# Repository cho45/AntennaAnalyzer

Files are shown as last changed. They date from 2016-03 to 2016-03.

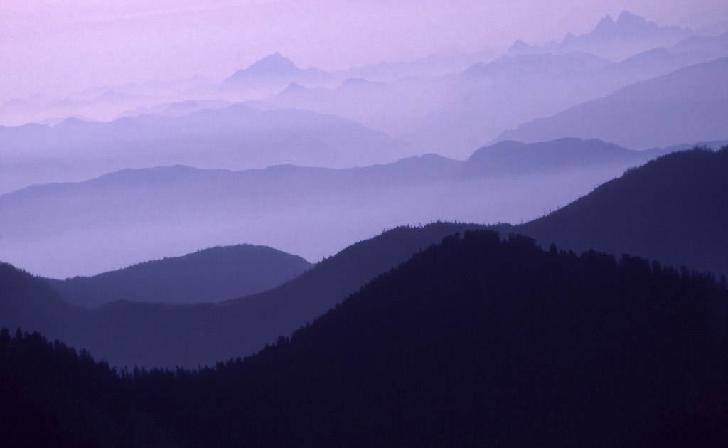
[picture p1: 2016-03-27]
software/cordova/www/bower_components/paper-scroll-header-panel/demo/images/bg1.jpg

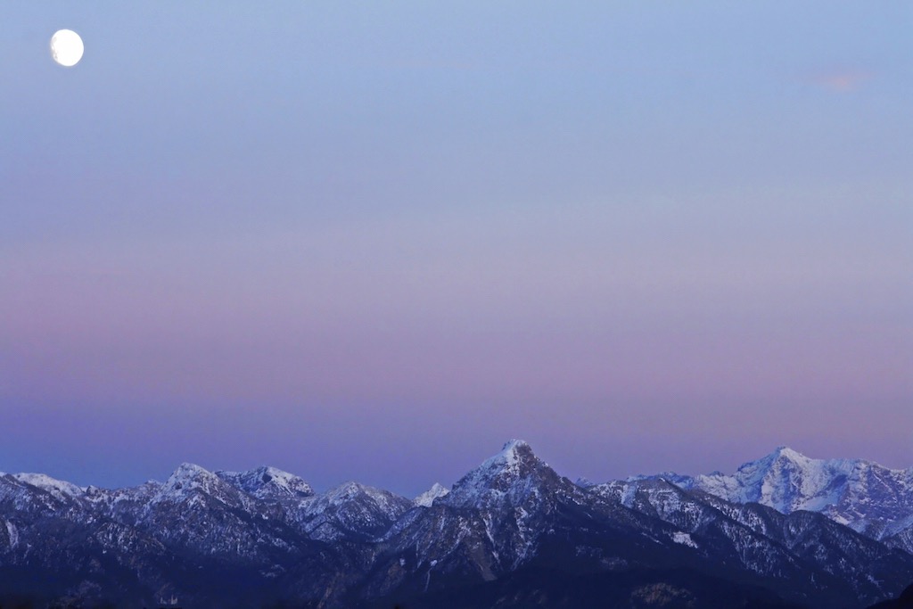
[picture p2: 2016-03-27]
software/cordova/www/bower_components/paper-scroll-header-panel/demo/images/bg3.jpg

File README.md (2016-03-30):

# AntennaAnalyzer

cho45's AntennaAnalyzer project

# Spec

 * Frequency range: 〜70MHz
 * Measures: SWR, R + j |X|

# Hardware

 * AD9851 DDS
 * Resistive bridge + AD8302 detector
 * LPC1114 (with mbed framework)
 * Bluetooth

# Android App Screen Shots







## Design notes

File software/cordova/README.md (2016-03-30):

## Development

```
npm install -g cordova
```

Emulate Bluetooth

```
cordova run browser
```

Device

```
cordova run android --device
```

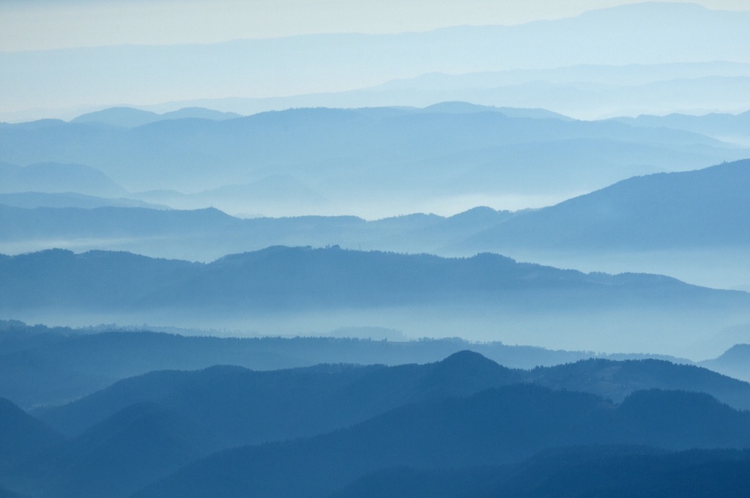
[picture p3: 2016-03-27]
software/cordova/www/bower_components/paper-scroll-header-panel/demo/images/bg4.jpg

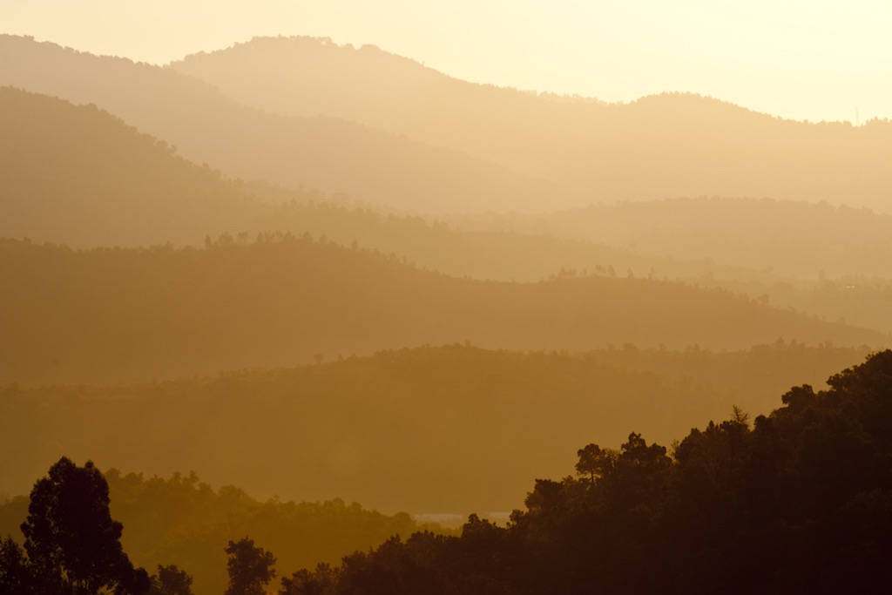
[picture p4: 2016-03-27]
software/cordova/www/bower_components/paper-scroll-header-panel/demo/images/bg2.jpg

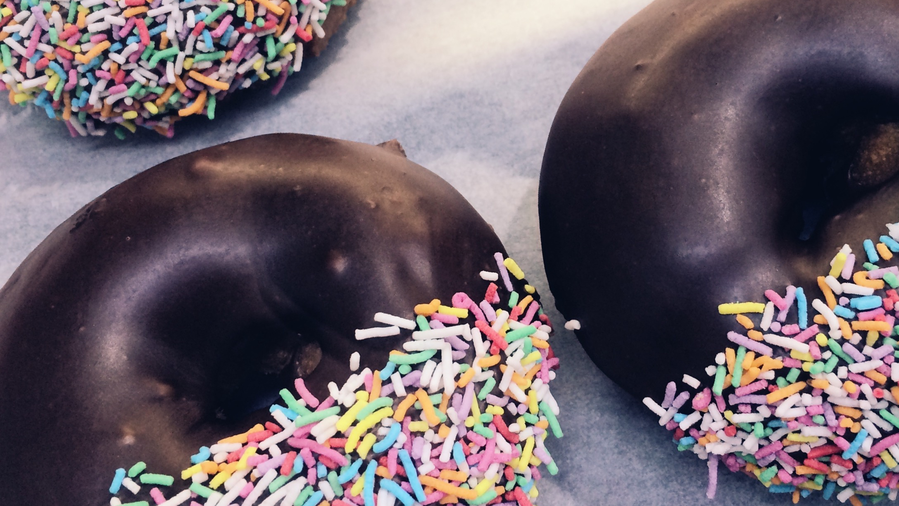
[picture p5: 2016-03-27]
software/cordova/www/bower_components/paper-card/demo/donuts.png

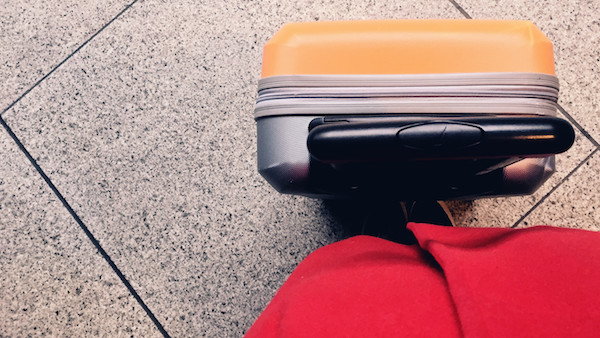
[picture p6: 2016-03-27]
software/cordova/www/bower_components/paper-card/demo/travel.png

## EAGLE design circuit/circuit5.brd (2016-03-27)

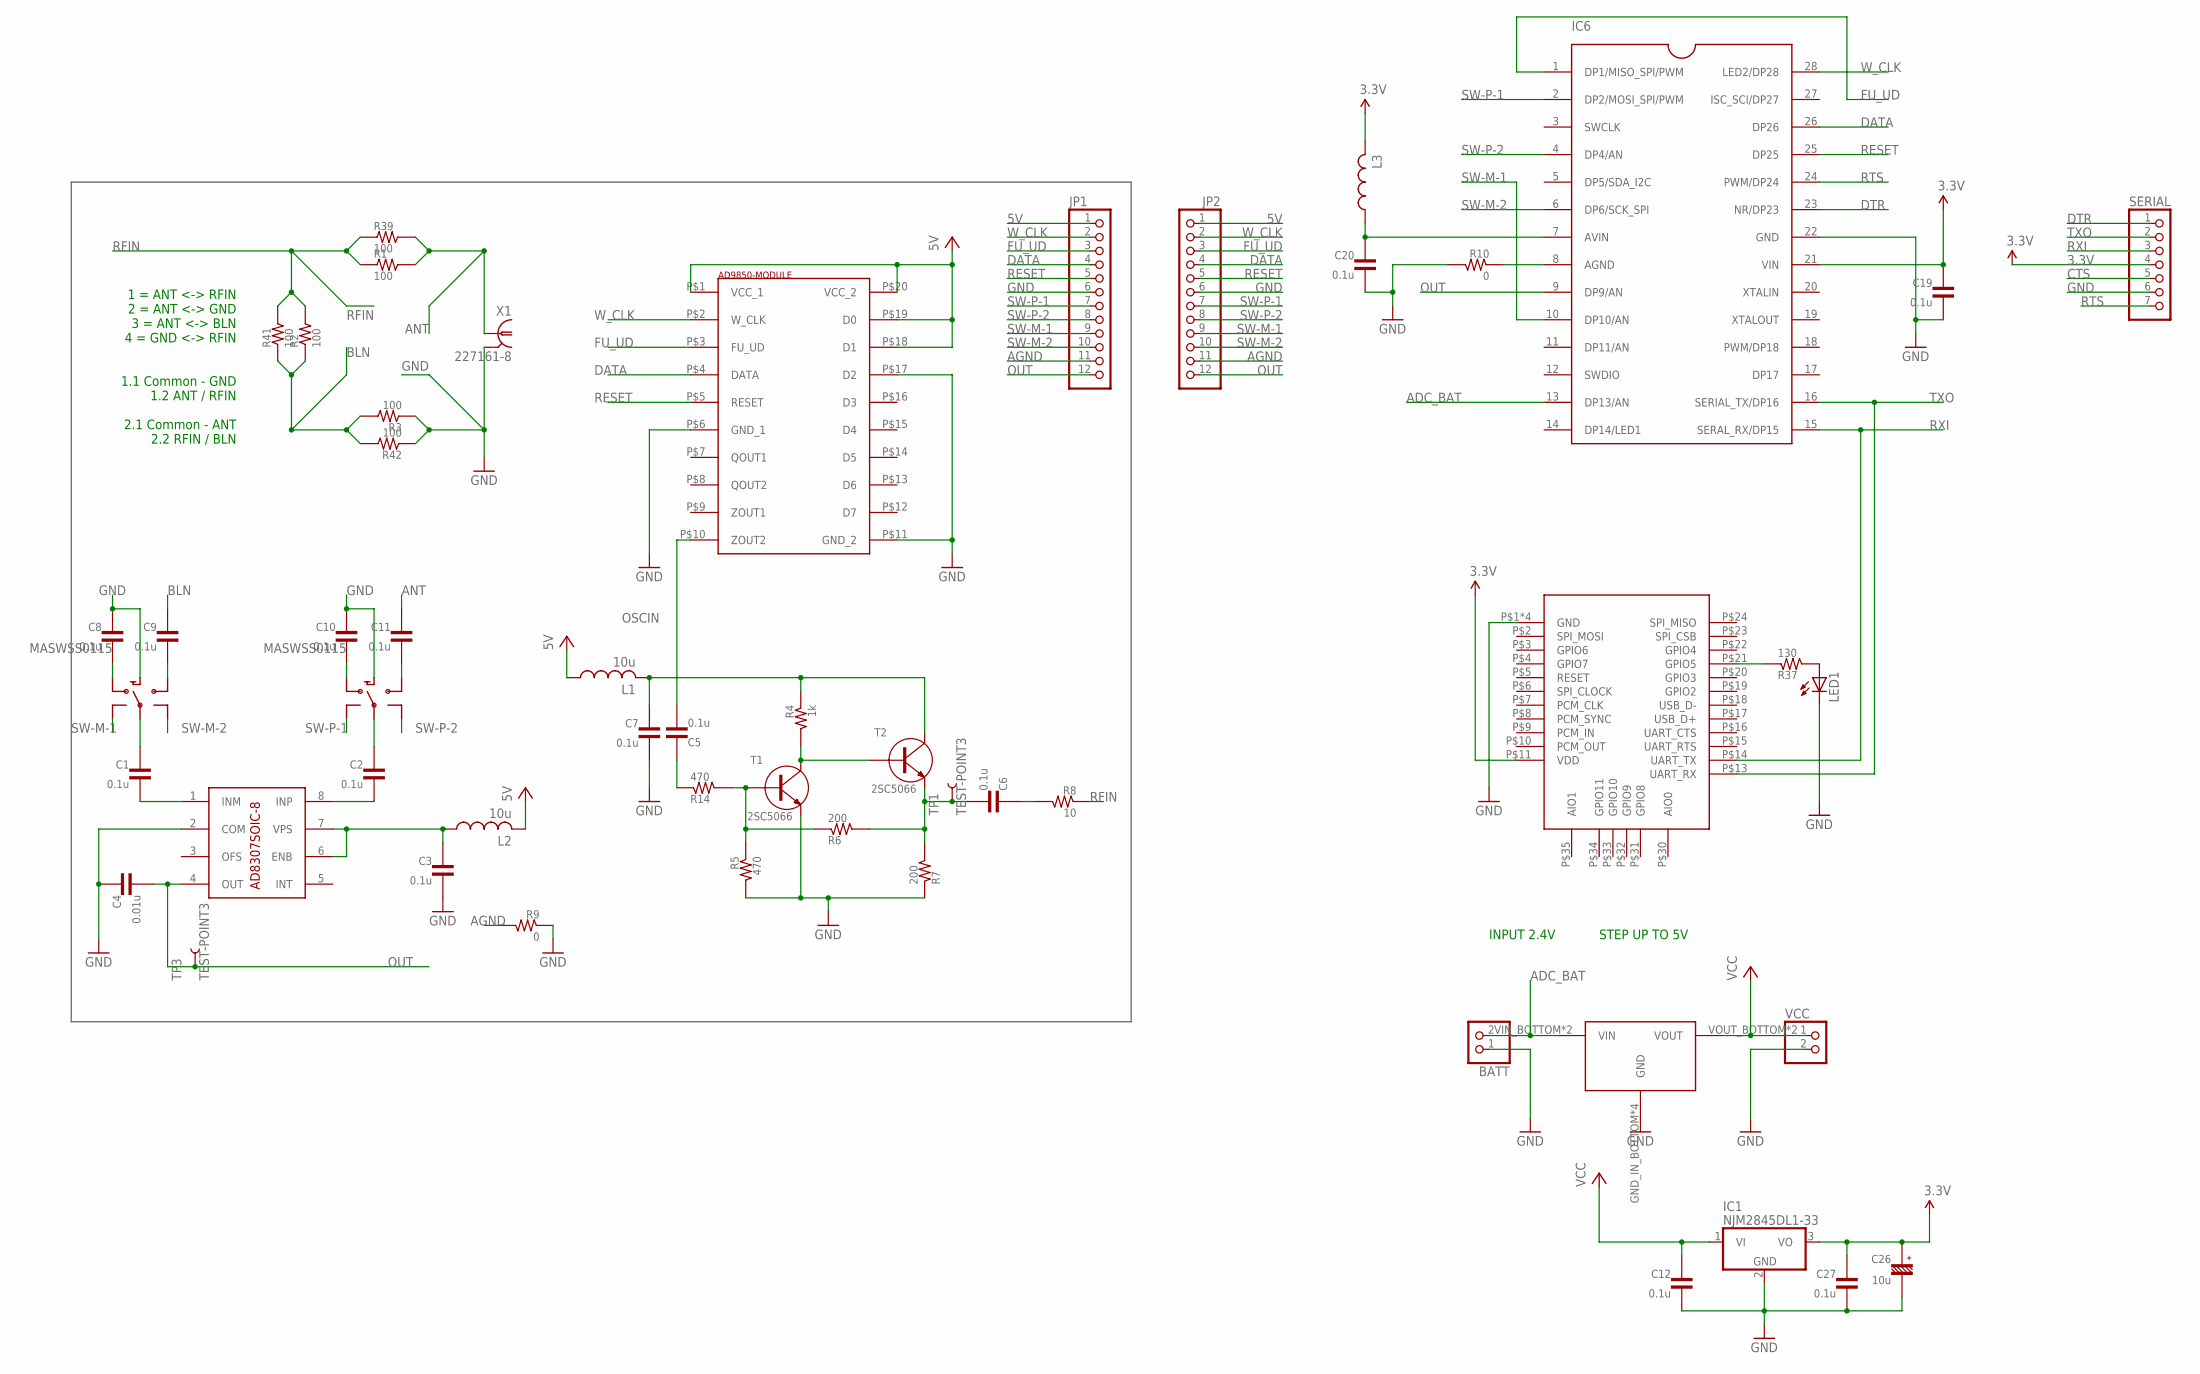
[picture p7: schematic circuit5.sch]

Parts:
BATT: PINHD-1X2; 1X02
C1, C2, C3, C5, C6, C7, C8, C9, C10, C11, C12, C19, C20, C27: 0.1u; CP1608
C4: 0.01u; CP1608
C26: 10u; 16V-4-2.54
IC1: NJM2845DL1-33; TO252
IC6: LPC1114FN28; DIP28
JP1, JP2: PINHD-1X12; 1X12
L1, L2: 10u; CP1608
L3: L-; CP1608
LED1: LED3MM
R1, R2, R3, R39, R41, R42: 100; CP1608
R4: 1k; CP1608
R5, R14: 470; CP1608
R6, R7: 200; CP1608
R8: 10; CP1608
R9, R10: 0; CP1608
R37: 130; CP1608
SERIAL: PINHD-1X7; 1X07
T1, T2: 2SC5066; SSM
TP1, TP3: TEST-POINT3; PAD.03X.03
U$1: AD9850-MODULE
U$2: RN-42
U$3: AD8307SOIC-8; SO08
U$4: DC-DCSX1308; DC-DC-SX1308
U$5, U$6: MASWSS0115; SOT363
VCC: PINHD-1X2; 1X02
X1: 227161-8; AMP_227161

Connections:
3.3V: C19.SMD1 (1), C26.+, C27.SMD1 (1), IC1.3 (VO), IC6.21 (VIN), L3.SMD2 (2), SERIAL.4, U$2.P$11 (VDD)
5V: C12.SMD1 (1), IC1.1 (VI), JP1.1, JP2.1, L1.SMD1 (1), L2.SMD2 (2), U$1.P$1 (VCC_1), U$1.P$18 (D1), U$1.P$19 (D0), U$1.P$20 (VCC_2), U$4.VOUT_BOTTOM (VOUT), U$4.VOUT_TOP (VOUT), VCC.1
+12V-ANALOG: C7.SMD1 (1), L1.SMD2 (2), R4.SMD1 (1), T2.P$3 (C)
ADC_BAT: BATT.2, IC6.13 (DP13/AN), U$4.VIN_BOTTOM (VIN), U$4.VIN_TOP (VIN)
AGND: IC6.8 (AGND), JP1.11, JP2.11, R9.SMD2 (2), R10.SMD1 (1)
ANT: C11.SMD1 (1), R1.SMD2 (2), R39.SMD2 (2), X1.1
BLN: C9.SMD1 (1), R2.SMD1 (1), R3.SMD2 (2), R41.SMD1 (1), R42.SMD2 (2)
CTS: SERIAL.5
DATA: IC6.26 (DP26), JP1.4, JP2.4, U$1.P$4 (DATA)
DTR: IC6.23 (NR/DP23), SERIAL.1
FU_UD: IC6.1 (DP1/MISO_SPI/PWM), JP1.3, JP2.3, U$1.P$3 (FU_UD)
GND: BATT.1, C3.SMD2 (2), C4.SMD1 (1), C7.SMD2 (2), C8.SMD1 (1), C10.SMD1 (1), C12.SMD2 (2), C19.SMD2 (2), C20.SMD2 (2), C26.-, C27.SMD2 (2), IC1.2 (GND), IC6.22 (GND), JP1.6, JP2.6, LED1.K (C), R3.SMD1 (1), R5.SMD2 (2), R7.SMD1 (1), R9.SMD1 (1), R10.SMD2 (2), R42.SMD1 (1), SERIAL.6, T1.P$2 (E), U$1.P$6 (GND_1), U$1.P$11 (GND_2), U$1.P$17 (D2), U$2.P$1 (GND), U$2.P$12 (GND), U$2.P$28 (GND), U$2.P$29 (GND), U$3.2 (COM), U$4.GND_IN_BOTTOM (GND), U$4.GND_IN_TOP (GND), U$4.GND_OUT_BOTTOM (GND), U$4.GND_OUT_TOP (GND), U$5.2 (GND), U$6.2 (GND), VCC.2, X1.2
unnamed: C2.SMD1 (1), U$6.5 (COMMON)
unnamed: C1.SMD1 (1), U$5.5 (COMMON)
unnamed: R4.SMD2 (2), T1.P$3 (C), T2.P$1 (B)
unnamed: R5.SMD1 (1), R6.SMD1 (1), R14.SMD2 (2), T1.P$1 (B)
unnamed: C8.SMD2 (2), U$5.3 (RF2)
unnamed: C6.SMD2 (2), R6.SMD2 (2), R7.SMD2 (2), T2.P$2 (E), TP1.P$1
unnamed: C1.SMD2 (2), U$3.1 (INM)
unnamed: C2.SMD2 (2), U$3.8 (INP)
unnamed: C3.SMD1 (1), L2.SMD1 (1), U$3.6 (ENB), U$3.7 (VPS)
unnamed: C9.SMD2 (2), U$5.1 (RF1)
unnamed: C10.SMD2 (2), U$6.3 (RF2)
unnamed: C5.SMD1 (1), R14.SMD1 (1)
unnamed: C11.SMD2 (2), U$6.1 (RF1)
unnamed: C6.SMD1 (1), R8.SMD2 (2)
unnamed: C20.SMD1 (1), IC6.7 (AVIN), L3.SMD1 (1)
unnamed: LED1.A, R37.SMD2 (2)
unnamed: R37.SMD1 (1), U$2.P$21 (GPIO5)
OSCIN: C5.SMD2 (2), U$1.P$10 (ZOUT2)
OUT: C4.SMD2 (2), IC6.9 (DP9/AN), JP1.12, JP2.12, TP3.P$1, U$3.4 (OUT)
RESET: IC6.25 (DP25), JP1.5, JP2.5, U$1.P$5 (RESET)
RFIN: R1.SMD1 (1), R2.SMD2 (2), R8.SMD1 (1), R39.SMD1 (1), R41.SMD2 (2)
RTS: IC6.24 (PWM/DP24), SERIAL.7
RXI: IC6.15 (SERAL_RX/DP15), SERIAL.3, U$2.P$14 (UART_TX)
SW-M-1: IC6.10 (DP10/AN), JP1.9, JP2.9, U$5.4 (V2)
SW-M-2: IC6.6 (DP6/SCK_SPI), JP1.10, JP2.10, U$5.6 (V1)
SW-P-1: IC6.2 (DP2/MOSI_SPI/PWM), JP1.7, JP2.7, U$6.4 (V2)
SW-P-2: IC6.4 (DP4/AN), JP1.8, JP2.8, U$6.6 (V1)
TXO: IC6.16 (SERIAL_TX/DP16), SERIAL.2, U$2.P$13 (UART_RX)
W_CLK: IC6.28 (LED2/DP28), JP1.2, JP2.2, U$1.P$2 (W_CLK)

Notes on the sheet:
1 = ANT <-> RFIN 2 = ANT <-> GND 3 = ANT <-> BLN 4 = GND <-> RFIN 1.1 Common - GND 1.2 ANT / RFIN 2.1 Common - ANT 2.2 RFIN / BLN
INPUT 2.4V
STEP UP TO 5V

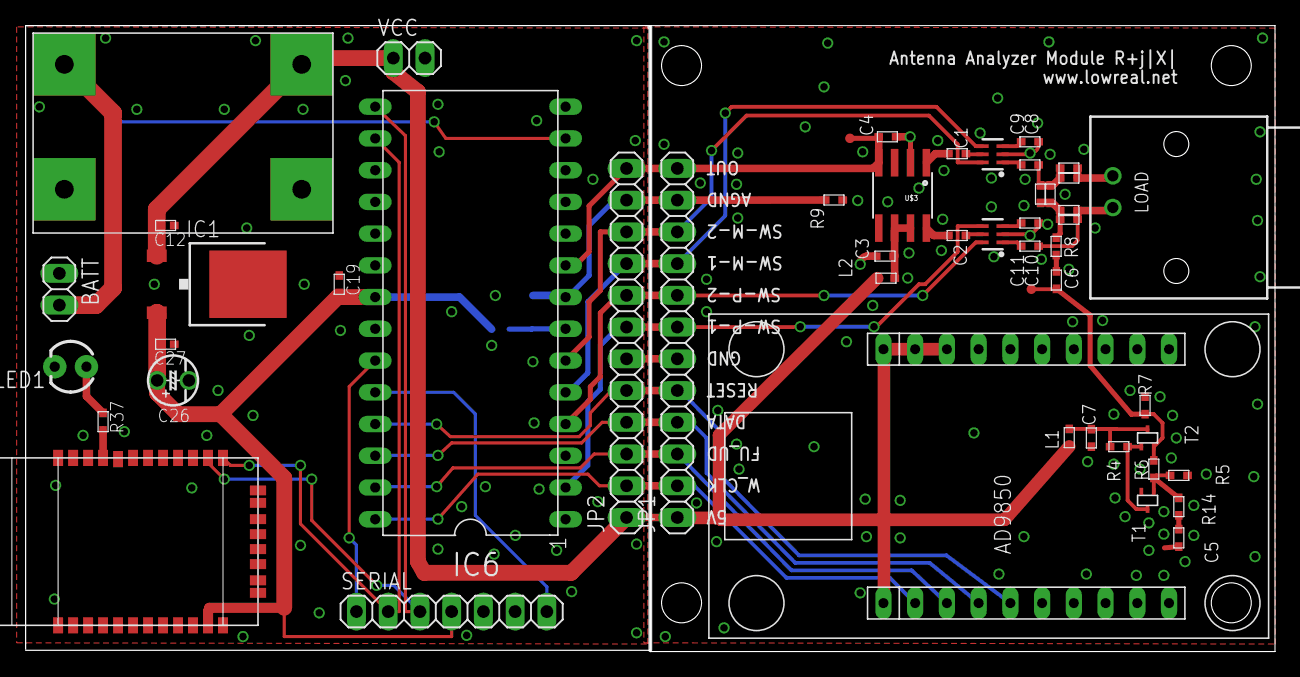
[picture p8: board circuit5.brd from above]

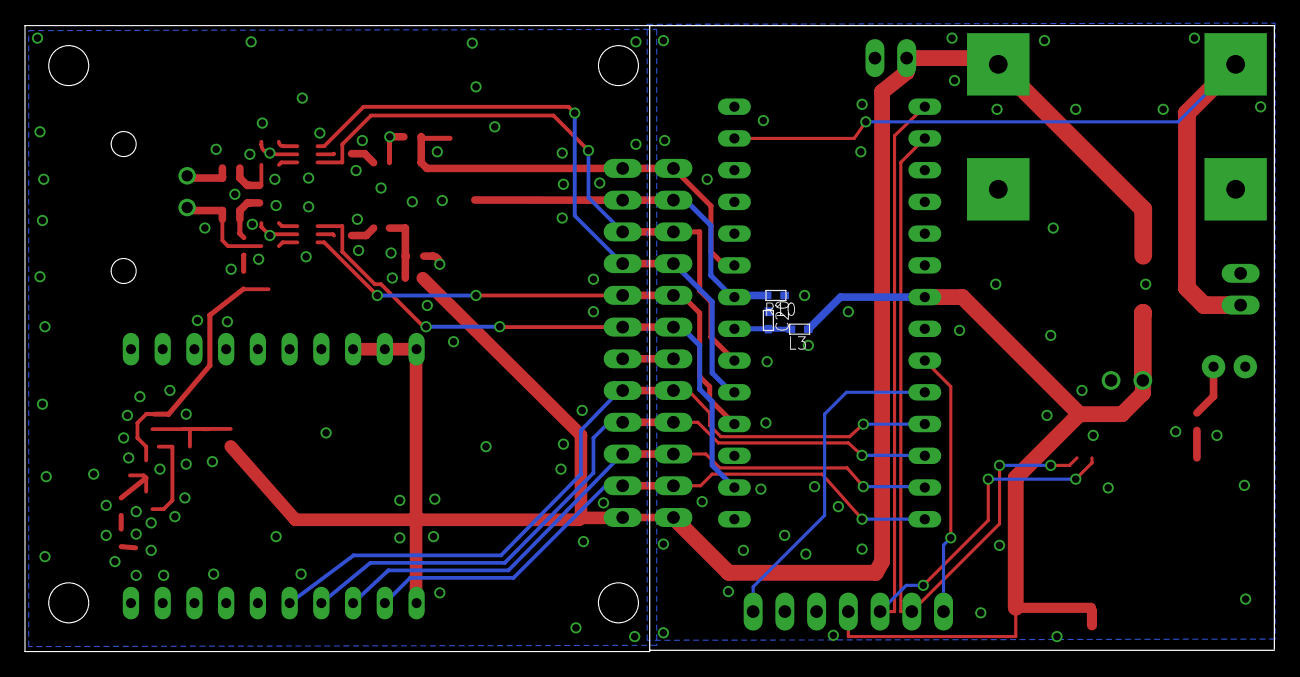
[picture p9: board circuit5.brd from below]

Board: 2 copper layers, 100.0 x 50.1 mm, 53 parts (3 on the bottom side), 40 nets.

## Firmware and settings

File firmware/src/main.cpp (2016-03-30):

#include "mbed.h"
#include <CircularBuffer.h>
#include <stdint.h>
#include <inttypes.h>
#include "ad9851.hpp"

Serial serial(USBTX, USBRX);
AnalogIn battery(dp13);

AnalogIn adc(dp9);
DigitalOut sw_p_1(dp2);
DigitalOut sw_p_2(dp4);
DigitalOut sw_m_1(dp10);
DigitalOut sw_m_2(dp6);

struct measure_task_t {
	volatile bool completed = 1;
	volatile bool interrupted = 0;
	volatile uint32_t start;
	volatile uint32_t end;
	volatile uint32_t step;
	volatile uint8_t  avg_count;
};
volatile measure_task_t measure_task;

void process_serial();

// RFC = INM
// RF1 = BLN
// RF2 = GND
// V1 = SW-M-2
// V2 = SW-M-1
// V1=0 / V2=1 RF1
// V1=1 / V2=0 RF2
// SW-M-2=0 / SW-M-1=1 BLN
// SW-M-2=1 / SW-M-1=0 GND
inline void inm_bln() {
	sw_m_1 = 1;
	sw_m_2 = 0;
}

inline void inm_gnd() {
	sw_m_1 = 0;
	sw_m_2 = 1;
}

// RFC = INP
// RF1 = ANT
// RF2 = GND
// V1 = SW-P-2
// V2 = SW-P-1
// V1=0 / V2=1 RF1
// V1=1 / V2=0 RF2
inline void inp_ant() {
	sw_p_1 = 1;
	sw_p_2 = 0;
}

inline void inp_gnd() {
	sw_p_1 = 0;
	sw_p_2 = 1;
}

inline void switch_to_eref() {
	inp_gnd();
	inm_bln();
}
inline void switch_to_load() {
	inp_ant();
	inm_gnd();
}
inline void switch_to_diff() {
	inp_ant();
	inm_bln();
}


AD9851<30000000, true> ad9851(/*data*/dp26, /*fq_ud*/dp1, /*w_clk*/dp28, /*reset*/dp25);
CircularBuffer<char, 80> serial_buffer;

//constexpr const static double Z_0 = 50.0;
//void calculate_complex_impedance(
//	double ref_dB,
//	double load_dB,
//	double diff_dB,
//
//	double& r,
//	double& x,
//	double& z,
//	double& vswr
//) {
//
//	// normalize
//	load_dB = load_dB - ref_dB;
//	diff_dB = diff_dB - ref_dB;
//
//	// antilog
//	double load = pow(10, load_dB / 10);
//	double diff = pow(10, diff_dB / 10);
//
//	// normalized diff is refrection coefficiant
//	vswr = (1 + diff) / (1 - diff);
//
//	double f = (2-load+2*diff);
//	r = ((1-diff)*Z_0) / f;
//	z = sqrt(load)*Z_0/sqrt(f);
//	x = sqrt(z * z - r * r);
//}

constexpr uint16_t SETTLING_TIME = 500;
void measure() {
	uint32_t start    = measure_task.start;
	uint32_t end      = measure_task.end;
	uint32_t step     = measure_task.step;
	uint8_t avg_count = measure_task.avg_count;
	measure_task.interrupted = 0;

	// power on ad9851
	ad9851.reset();
	for (uint32_t freq = start; freq <= end; freq += step) {
		uint32_t e_ref = 0, e_load = 0, e_diff = 0;

		ad9851.set_frequency(freq);

		switch_to_eref();
		wait_us(SETTLING_TIME);
		for (int i = 0; i < avg_count; i++)
			e_ref += adc.read_u16();

		switch_to_load();
		wait_us(SETTLING_TIME);
		for (int i = 0; i < avg_count; i++)
			e_load += adc.read_u16();

		switch_to_diff();
		wait_us(SETTLING_TIME);
		for (int i = 0; i < avg_count; i++)
			e_diff += adc.read_u16();

		serial.printf("<MEAS>,%d,%d,%d,%d\n", freq, e_ref / avg_count, e_load / avg_count, e_diff / avg_count);
		if (measure_task.interrupted) break;
	}
	serial.printf("<MEAS>,END\n");
	ad9851.powerdown();
}

void process_serial() {
	while (serial.readable()) {
		char c = serial.getc();
		serial.putc(c);
		if (c == 0x0D) continue; // ignore CR
		if (c == 0x0A) { // treat LF as line end
			static char line[80];
			int i = 0;
			for (char c; serial_buffer.pop(c); i++) {
				line[i] = c;
			}
			line[i] = '\0';
			serial_buffer.reset();

			serial.printf("COMMAND: %s\n", line);

			char* tokens[10];
			tokens[0] = line;
			for (size_t i = 0, t = 0, len = strlen(line); i < len; i++) {
				if (line[i] == ',') {
					line[i] = 0;
					tokens[++t] = line + i + 1;
					if (t < 10) {
						continue;
					} else {
						break;
					}
				}
			}

			if (strcmp(tokens[0], "MEAS") == 0) {
				if (strcmp(tokens[1], "END") == 0) {
					measure_task.interrupted = 1;
					return;
				}
				if (!measure_task.completed) {
					serial.printf("ALREADY RUNNING MEASURE\n");
					return;
				}

				uint32_t start     = std::atoi(tokens[1]);
				uint32_t end       = std::atoi(tokens[2]);
				uint32_t step      = std::atoi(tokens[3]);
				uint8_t  avg_count = std::atoi(tokens[4]);
				if (avg_count <= 0) {
					avg_count = 1;
				}
				if (start < end && step > 0) {
					measure_task.start = start;
					measure_task.end = end;
					measure_task.step = step;
					measure_task.avg_count = avg_count;
					measure_task.completed = 0;
				} else {
					serial.printf("INVALID ARGUMENT start=%s end=%s step=%s\n", tokens[1], tokens[2], tokens[3]);
				}
			} else
			if (strcmp(tokens[0], "OSC") == 0) {
				if (strcmp(tokens[1], "ON") == 0) {
					ad9851.reset();
					uint32_t freq = std::atoi(tokens[2]);
					if (freq > 0) {
						serial.printf("<OSC>,ON,%d\n", freq);
						ad9851.set_frequency(freq);
					} else {
						serial.printf("INVALID ARGUMENT freq=%d\n", freq);
					}
				} else {
					serial.printf("<OSC>,OFF\n");
					ad9851.powerdown();
				}
			} else {
				serial.printf("UNKOWN COMMAND %s\n", tokens[0]);
			}
			continue;
		}
		serial_buffer.push(c);
	}
}



int main() {
	serial.baud(115200);

	ad9851.reset();
	ad9851.powerdown();

	serial.printf("init\n");
	serial.attach( []() {
		process_serial();
	});

	for (;;) {
		if (!measure_task.completed) {
			measure();
			measure_task.completed = 1;
		}
		sleep();

//		uint16_t bat = static_cast<uint16_t>(battery.read() * 5000);
//		serial.printf("bat = %d\n", bat);
//
//		uint32_t start = 7000000;
//		uint32_t end   = 7300000;
//		uint32_t step  = (end - start) / 100;
//		measure(start, end, step);
	}
}

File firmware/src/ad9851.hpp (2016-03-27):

template <uint32_t CLKIN, bool MULTIPLIER>
class AD9851 {
	static constexpr double PHASE_FACTOR = 0x100000000 / (double)(CLKIN * (MULTIPLIER ? 6 : 1));

	DigitalOut PIN_DATA;
	DigitalOut PIN_FQ_UD;
	DigitalOut PIN_W_CLK;
	DigitalOut PIN_RESET;

	void serial_write(uint32_t freq, uint8_t phase, bool powerdown) {
		// freq (delta phase)
		for (int i = 0; i < 32; i++) {
			PIN_DATA = (freq>>i & 1);
			PIN_W_CLK = 1; wait_us(4);
			PIN_W_CLK = 0; wait_us(4);
		}

		// control bits
		PIN_DATA = MULTIPLIER ? 1 : 0;
		PIN_W_CLK = 1; wait_us(4);
		PIN_W_CLK = 0; wait_us(4);
		PIN_DATA = 0;
		PIN_W_CLK = 1; wait_us(4);
		PIN_W_CLK = 0; wait_us(4);

		// powerdown
		PIN_DATA = powerdown ? 1 : 0;
		PIN_W_CLK = 1; wait_us(4);
		PIN_W_CLK = 0; wait_us(4);

		// phase
		for (int i = 0; i < 5; i++) {
			PIN_DATA = (phase>>i & 1);
			PIN_W_CLK = 1; wait_us(4);
			PIN_W_CLK = 0; wait_us(4);
		}

		PIN_FQ_UD = 1; wait_us(4);
		PIN_FQ_UD = 0; wait_us(4);
	}

public:
	AD9851(
			PinName data,
			PinName fq_ud,
			PinName w_clk,
			PinName reset
		) :
			PIN_DATA(DigitalOut(data)),
			PIN_FQ_UD(DigitalOut(fq_ud)),
			PIN_W_CLK(DigitalOut(w_clk)),
			PIN_RESET(DigitalOut(reset))
	{
		PIN_DATA = 0;
		PIN_FQ_UD = 0;
		PIN_W_CLK = 0;
		PIN_RESET = 0;
	}

	/**
	 * W0 ... W31  -> Freq (LSB first)
	 * W32, W33    -> Control (for factory test)
	 * W34         -> Power-Down
	 * W35 ... W39 -> Phase (LSB first)
	 */

	void reset() {
		// ensure low
		PIN_DATA = 0;
		PIN_FQ_UD = 0;
		PIN_W_CLK = 0;

		// reset
		PIN_RESET = 1; wait(1);
		PIN_RESET = 0; wait(1);

		// reset to serial mode
		// Pins of D0, D1 = 1, D2 = 0 for serial mode
		PIN_W_CLK = 1; wait_us(4);
		PIN_W_CLK = 0; wait_us(4);

		PIN_FQ_UD = 1; wait_us(4);
		PIN_FQ_UD = 0; wait_us(4);
	}

	void set_frequency(uint32_t frequency) {
		set_frequency(frequency, 0);
	}

	void set_frequency(uint32_t frequency, uint8_t phase) {
		uint32_t deltaPhase = PHASE_FACTOR * frequency;
		serial_write(deltaPhase, phase, 0);
	}

	void powerdown() {
		serial_write(0, 0, 1);
	}
};

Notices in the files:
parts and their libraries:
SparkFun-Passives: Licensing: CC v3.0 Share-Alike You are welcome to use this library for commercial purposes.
